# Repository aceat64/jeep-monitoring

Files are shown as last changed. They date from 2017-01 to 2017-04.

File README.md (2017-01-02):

# Raspberry Pi Jeep Monitoring System

This system is designed for monitoring or interacting with various functions of my specific Jeep Wrangler, such as the dual battery system and the IHS (Internal High-Speed) CAN bus. All information is available via an API, for consumption by mobile devices or Android headunits on my Jeep's local wifi network.

## Features
- Voltage monitoring of two batteries, for dual battery systems.
- Current monitoring via a shunt resistor, tweaking the code may be required depending on your specific shunt resistor.
- Status of the battery isolator, a 12V digital input.
- Accelerometer, for determining vehicle tilt.
- GPS header, for external GPS module.
- CAN Bus transciever.

## Preview

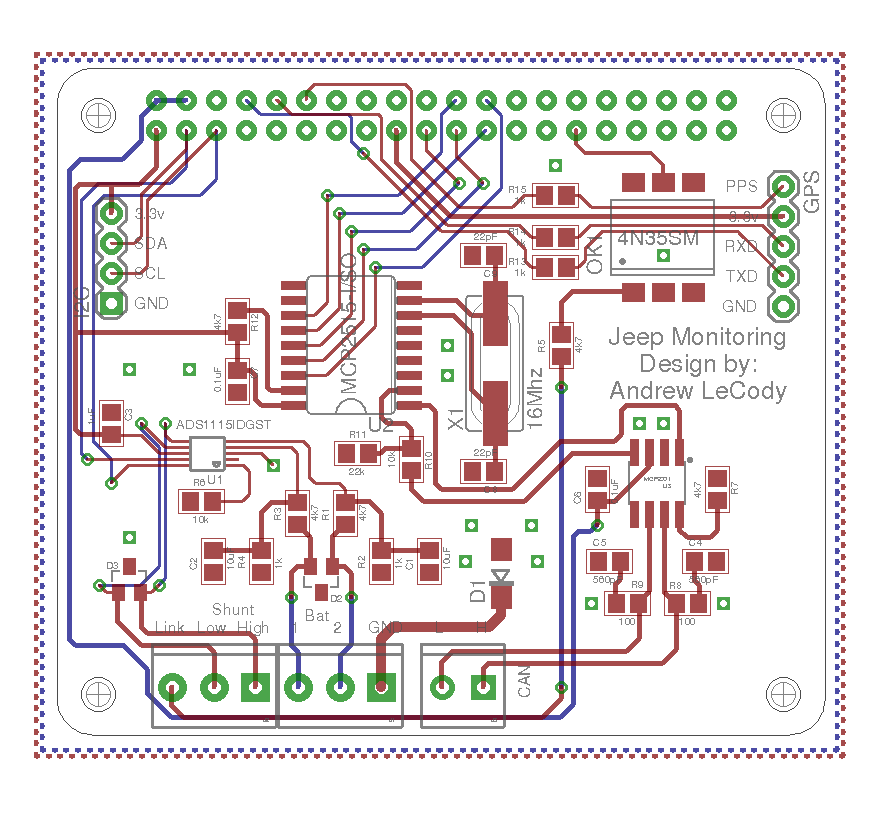
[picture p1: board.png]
board


### Top

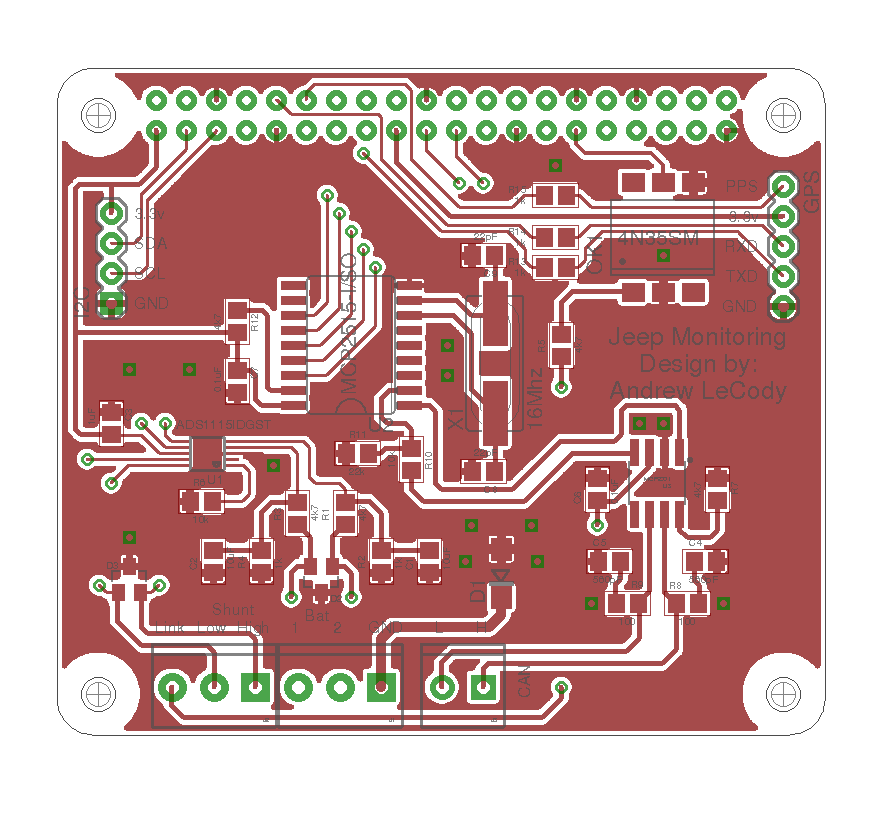
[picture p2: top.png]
top


### Bottom

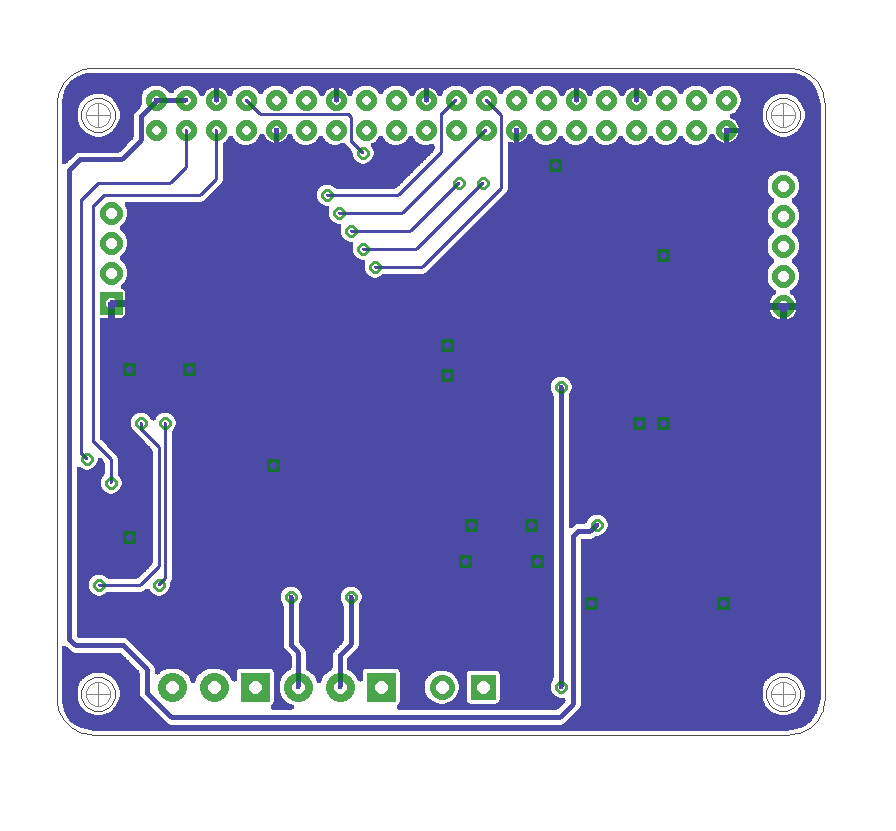
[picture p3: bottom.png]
bottom


## Bill Of Materials
See this [Google doc](https://docs.google.com/spreadsheets/d/1EL97Gz-JKfgCOYKvCzc1mUYXWVdC4jQAL_xUaZWqmfQ/edit?usp=sharing) for more info.

## License
Copyright Andrew LeCody 2017

All schematics, circuit board design files and documentation are released under the [Creative Commons Attribution-ShareAlike 4.0 International License](https://creativecommons.org/licenses/by-sa/4.0/).

All source code is releaed under the [GNU General Public License version 3](https://www.gnu.org/licenses/gpl-3.0-standalone.html).

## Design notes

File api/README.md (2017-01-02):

# Raspberry Pi Jeep Monitoring System API

This is the software that runs on the Raspberry Pi to provide an API for accessing various information about the current state of my Jeep.

## License
Copyright Andrew LeCody 2017

This program is free software: you can redistribute it and/or modify it under the terms of the GNU General Public License as published by the Free Software Foundation, either version 3 of the License, or (at your option) any later version.

This program is distributed in the hope that it will be useful, but WITHOUT ANY WARRANTY; without even the implied warranty of MERCHANTABILITY or FITNESS FOR A PARTICULAR PURPOSE.  See the [GNU General Public License](https://www.gnu.org/licenses/gpl-3.0-standalone.html) for more details.

You should have received a copy of the GNU General Public License along with this program.  If not, see: http://www.gnu.org/licenses/

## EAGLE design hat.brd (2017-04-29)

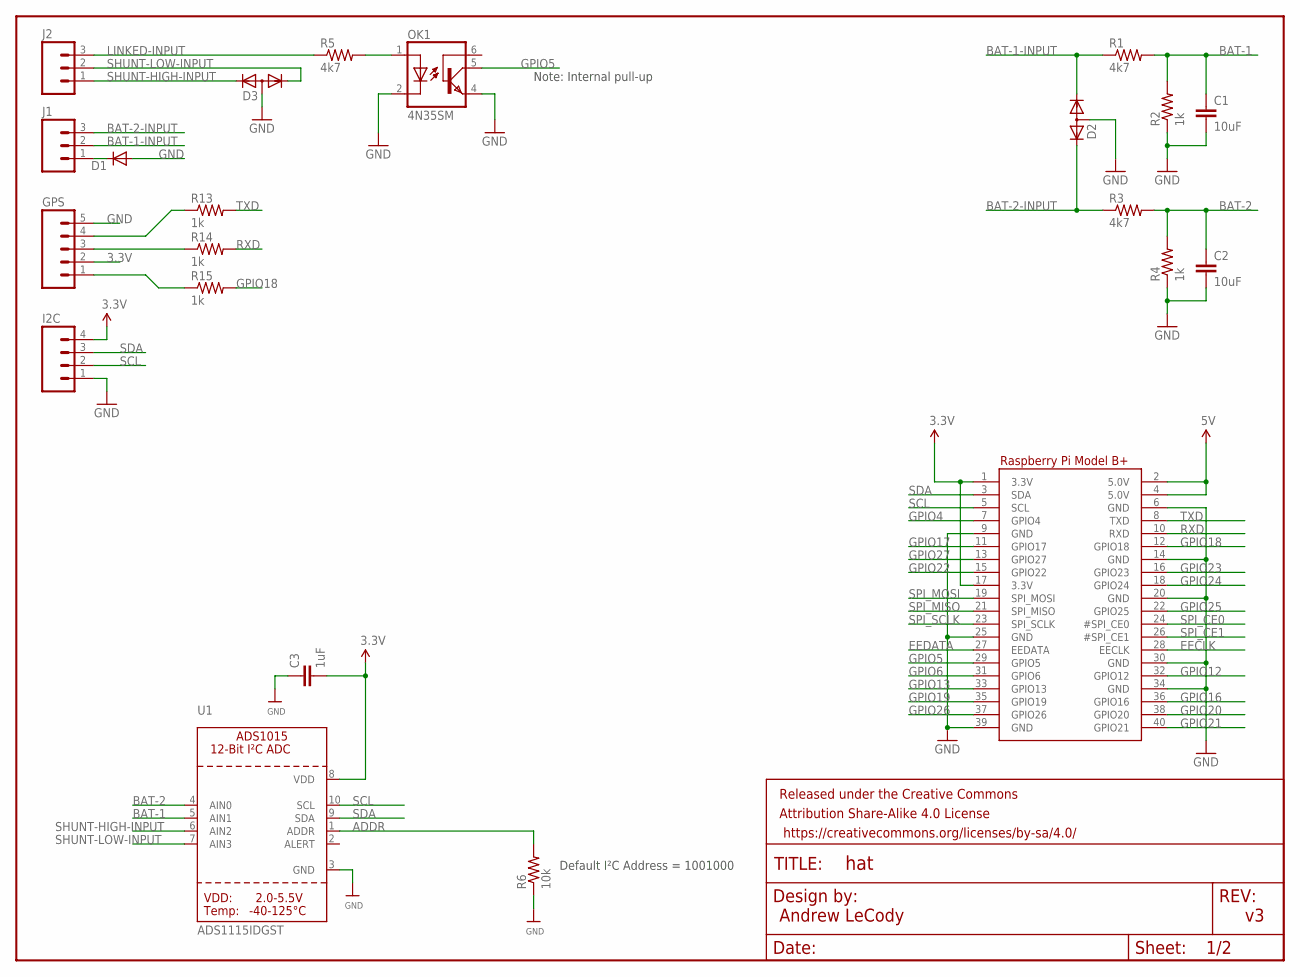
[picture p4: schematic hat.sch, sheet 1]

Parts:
C1, C2: 10uF; C0805
C3: 1uF; C0805
D1: DIODE-DO214AC; DO214AC
D2, D3: DIODE-2CA|ACSOT23; SOT23
FRAME1: FRAME-LETTERNO_PACKAGE; DUMMY
GPS: M05PTH; 1X05
I2C: M04PTH; 1X04
J1, J2: M03SCREW; SCREWTERMINAL-3.5MM-3
OK1: 4N35SM; DIL6-SMD
R1, R3, R5: 4k7; R0805
R2, R4, R13, R14, R15: 1k; R0805
R6: 10k; R0805
RPI1: RASPBERRYPI_BPLUS_HATNOSLOTS; PI_HAT_NOSLOTS
U1: ADS1115IDGST; MSOP10

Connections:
3.3V: C3.2, GPS.2, I2C.4, RPI1.1 (3.3V), RPI1.17 (3.3V), U1.8 (VDD); also elsewhere on the board
5V: RPI1.2 (5.0V), RPI1.4 (5.0V); also elsewhere on the board
ADDR: R6.2, U1.1 (ADDR)
BAT-1: C1.1, R1.2, R2.2, U1.5 (AIN1)
BAT-1-INPUT: D2.1 (K1), J1.2, R1.1
BAT-2: C2.1, R3.2, R4.2, U1.4 (AIN0)
BAT-2-INPUT: D2.2 (K2), J1.3, R3.1
EECLK: RPI1.28 (EECLK)
EEDATA: RPI1.27 (EEDATA)
GND: C1.2, C2.2, C3.1, D1.A, D2.3 (A), D3.3 (A), GPS.5, I2C.1, OK1.2 (C), OK1.4 (EMI), R2.1, R4.1, R6.1, RPI1.6 (GND), RPI1.9 (GND), RPI1.14 (GND), RPI1.20 (GND), RPI1.25 (GND), RPI1.30 (GND), RPI1.34 (GND), RPI1.39 (GND), U1.3 (GND); also elsewhere on the board
GPIO4: RPI1.7 (GPIO4)
GPIO5: OK1.5 (COL), RPI1.29 (GPIO5)
GPIO6: RPI1.31 (GPIO6)
GPIO12: RPI1.32 (GPIO12)
GPIO13: RPI1.33 (GPIO13)
GPIO16: RPI1.36 (GPIO16)
GPIO17: RPI1.11 (GPIO17)
GPIO18: R15.2, RPI1.12 (GPIO18)
GPIO19: RPI1.35 (GPIO19)
GPIO20: RPI1.38 (GPIO20)
GPIO21: RPI1.40 (GPIO21)
GPIO22: RPI1.15 (GPIO22)
GPIO23: RPI1.16 (GPIO23)
GPIO24: RPI1.18 (GPIO24)
GPIO25: RPI1.22 (GPIO25); also elsewhere on the board
GPIO26: RPI1.37 (GPIO26)
GPIO27: RPI1.13 (GPIO27)
LINKED-INPUT: J2.3, R5.1
unnamed: GPS.4, R13.1
unnamed: GPS.3, R14.1
unnamed: OK1.1 (A), R5.2
unnamed: GPS.1, R15.1
RXD: R14.2, RPI1.10 (RXD)
SCL: I2C.2, RPI1.5 (SCL), U1.10 (SCL)
SDA: I2C.3, RPI1.3 (SDA), U1.9 (SDA)
SHUNT-HIGH-INPUT: D3.2 (K2), J2.1, U1.6 (AIN2)
SHUNT-LOW-INPUT: D3.1 (K1), J2.2, U1.7 (AIN3)
SPI_CE0: RPI1.24 (#SPI_CE0); also elsewhere on the board
SPI_CE1: RPI1.26 (#SPI_CE1)
SPI_MISO: RPI1.21 (SPI_MISO); also elsewhere on the board
SPI_MOSI: RPI1.19 (SPI_MOSI); also elsewhere on the board
SPI_SCLK: RPI1.23 (SPI_SCLK); also elsewhere on the board
TXD: R13.2, RPI1.8 (TXD)
VEHICLE-GND: D1.C, J1.1

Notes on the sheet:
Andrew LeCody
Default I²C Address = 1001000
Note: Internal pull-up

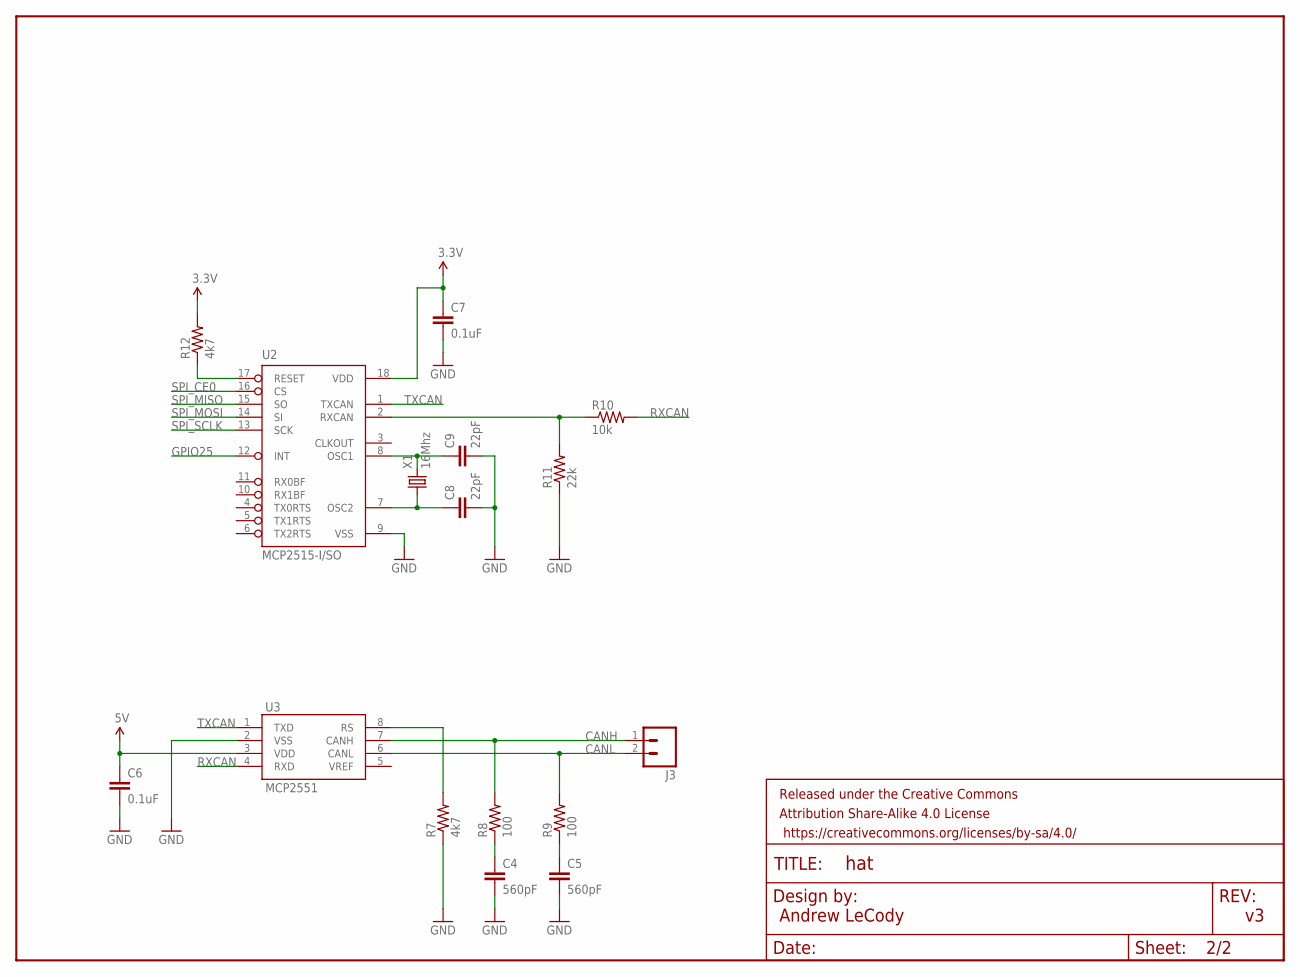
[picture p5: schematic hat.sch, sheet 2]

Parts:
C4, C5: 560pF; C0805
C6, C7: 0.1uF; C0805
C8, C9: 22pF; C0805
FRAME2: FRAME-LETTERNO_PACKAGE; DUMMY
J3: M023.5MM; SCREWTERMINAL-3.5MM-2
R7, R12: 4k7; R0805
R8, R9: 100; R0805
R10: 10k; R0805
R11: 22k; R0805
U2: MCP2515-I/SO; SO18L
U3: MCP2551; SO08
X1: 16Mhz; HC49-4-HSMX

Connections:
3.3V: C7.1, R12.2, U2.18 (VDD); also elsewhere on the board
5V: C6.1, U3.3 (VDD); also elsewhere on the board
CANH: J3.1, R8.2, U3.7 (CANH)
CANL: J3.2, R9.2, U3.6 (CANL)
GND: C4.2, C5.2, C6.2, C7.2, C8.2, C9.2, R7.1, R11.1, U2.9 (VSS), U3.2 (VSS); also elsewhere on the board
GPIO25: U2.12 (INT); also elsewhere on the board
unnamed: R10.1, R11.2, U2.2 (RXCAN)
unnamed: C4.1, R8.1
unnamed: C5.1, R9.1
unnamed: C9.1, U2.8 (OSC1), X1.2
unnamed: C8.1, U2.7 (OSC2), X1.1
RS: R7.2, U3.8 (RS)
RXCAN: R10.2, U3.4 (RXD)
SPI_CE0: U2.16 (CS); also elsewhere on the board
SPI_MISO: U2.15 (SO); also elsewhere on the board
SPI_MOSI: U2.14 (SI); also elsewhere on the board
SPI_SCLK: U2.13 (SCK); also elsewhere on the board
TXCAN: U2.1 (TXCAN), U3.1 (TXD)
U2_RST: R12.1, U2.17 (RESET)

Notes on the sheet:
Andrew LeCody

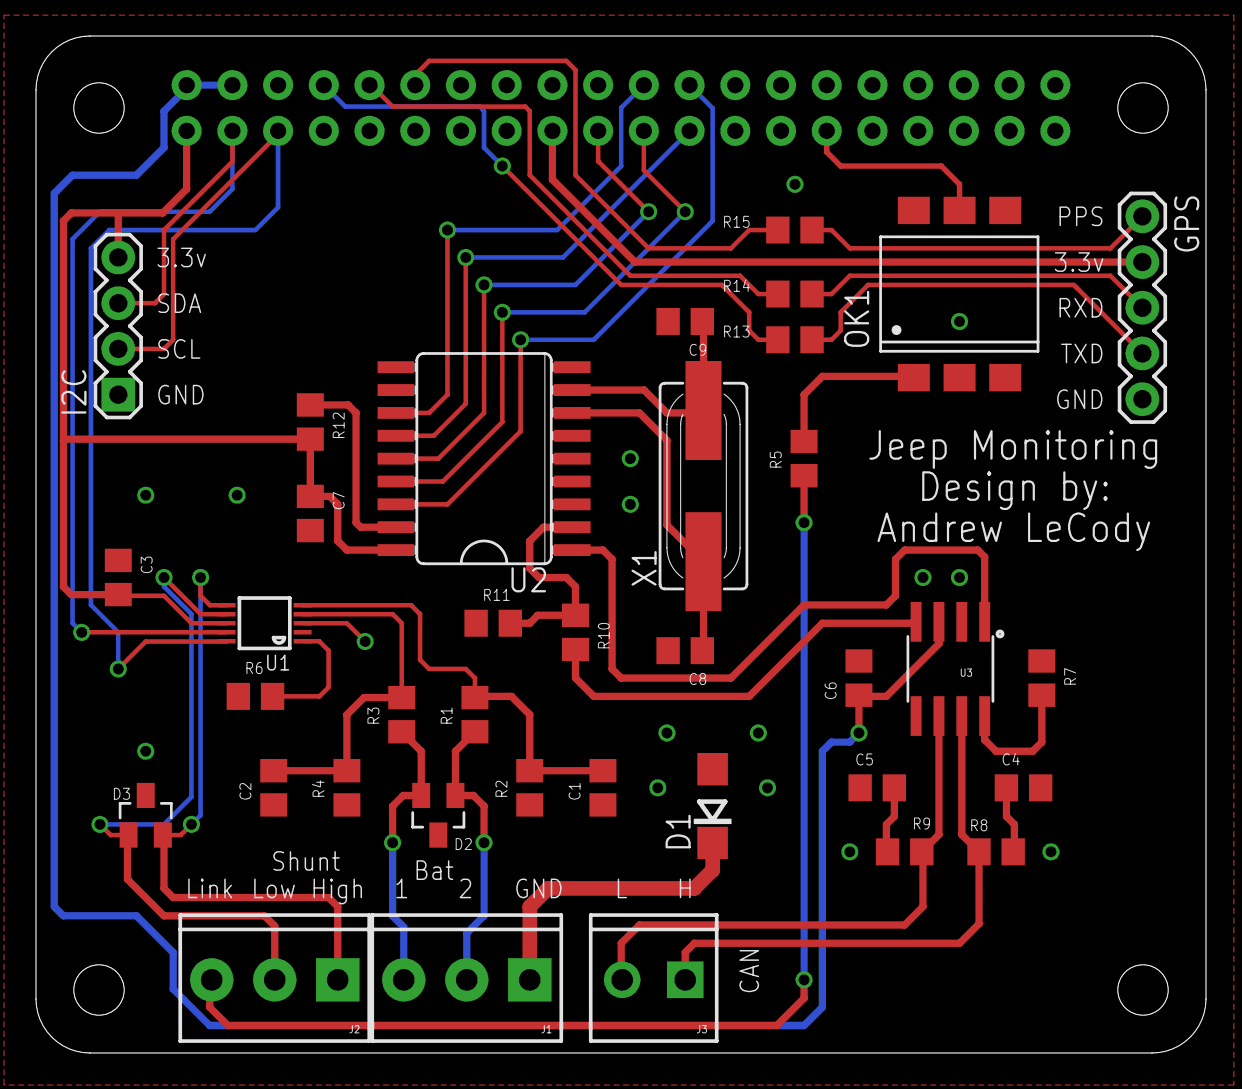
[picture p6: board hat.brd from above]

Board: 2 copper layers, 65.0 x 56.5 mm, 40 parts (0 on the bottom side), 38 nets.

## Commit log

2016-10-28 Renamed hat2 to hat_smd
    [hat_smd.brd, hat_smd.sch]
2016-12-06 Current monitoring
    [hat_v2.brd, hat_v2.sch]
2016-12-09 V2 board done
    [hat_v2.brd, hat_v2.sch]
2016-12-18 Minor tweak to PCB
    [hat_v2.brd]
2016-12-18 Version 3 mostly done
    [hat_v3.brd, hat_v3.sch]
2016-12-19 Minor tweaks to v2
    [hat_v2.brd, hat_v2.sch]
2016-12-19 V3 almost done, just need to finish MCP2515
    [hat_v3.brd, hat_v3.sch]
2016-12-19 V3 done!
    [hat_v3.brd, hat_v3.sch]
2016-12-19 Switch to round vias for all non-GND vias
    [hat_v3.brd]
2016-12-19 Switch to round vias for all non-GND vias (v2)
    [hat_v2.brd]
2016-12-20 Reworked v3
    [hat_v3.brd, hat_v3.sch]
2016-12-21 Tweaked placement of a via for ground
    [hat_v3.brd, hat_v3.sch]
2016-12-22 Minor tweaks to GND plane
    [hat_v3.brd, hat_v3.sch]
2016-12-24 Switched to 3.5mm screw terminals
    [hat_v3.brd, hat_v3.sch]
2017-01-02 Version 3 ready for public
    [hat.brd, hat.sch, hat_smd.brd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]
2017-01-02 Cleanup text
    [hat.brd, hat.sch]
2017-01-02 Added PNG files for board
2017-01-02 Added link to BOM
2017-01-03 Added 1kOhm resistors on inputs
    [hat.brd, hat.sch]
2017-01-03 Changed to packages with larger pads for easier hand soldering
    [hat.brd, hat.sch]
2017-01-03 Tweaked spacing for two resistors
    [hat.brd]
2017-01-04 Replaced TVS diodes VD1/VD2 with single TVS diode D3
    [hat.brd, hat.sch]
2017-01-04 Properly connect U5 to 3V3
    [hat.brd]
2017-01-05 Added X/Y/Z markings for adxl345
    [hat.brd, hat.sch]
2017-01-14 Replaced accelerometer with i2c header
    [hat.brd, hat.sch]
2017-01-17 Minor tweak to silkscreen
    [hat.brd]
2017-02-18 Minor tweak to ground plane
    [hat.brd]
2017-04-29 Fixed power for MCP2551
    [hat.brd, hat.sch]

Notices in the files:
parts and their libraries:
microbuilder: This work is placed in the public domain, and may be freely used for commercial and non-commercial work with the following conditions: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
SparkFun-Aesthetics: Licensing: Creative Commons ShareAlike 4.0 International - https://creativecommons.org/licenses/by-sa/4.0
